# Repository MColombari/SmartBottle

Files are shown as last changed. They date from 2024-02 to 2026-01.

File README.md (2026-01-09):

# SmartBottle

Smart Bottle is a project developed by Pirelli Marco and Colombari Martina. for the course of IoT and 3D Intelligent System.
The project objective is to develop an ecosystem which help users improve their water drinking habit with an infrastructure of water dispenser and personal water bottle.

The Bottle is designed with modularity in mind, this helped achieve upgradability and reperability, while maintaining all the required feature.
The design has a very user oriented set of feature designed designed to make all the interaction as friendly and non invasive as possible, like the magnet connector to charge the system or the notification led ring that provide feedback to the user.
Thank to its modular design and open source internal architecture, we encourage user to get their hans on the system customize it.

<a target="_blank" href="https://icons8.com/icon/flyFkP7sj07V/settings">Settings</a> icon by <a target="_blank" href="https://icons8.com">Icons8</a>

<a target="_blank" href="https://icons8.com/icon/21100/refresh">Refresh</a> icon by <a target="_blank" href="https://icons8.com">Icons8</a>

## App Redesign

In this [folder](AppRedesign) you can find this system's app redesign, it contains the figma file and the relative presentation can be visualized in this [link](https://docs.google.com/presentation/d/1zaVYTiuax_qeKSTWNvRFGTr2BWS3d9cVZgYpMrOdAcI/edit?usp=sharing).

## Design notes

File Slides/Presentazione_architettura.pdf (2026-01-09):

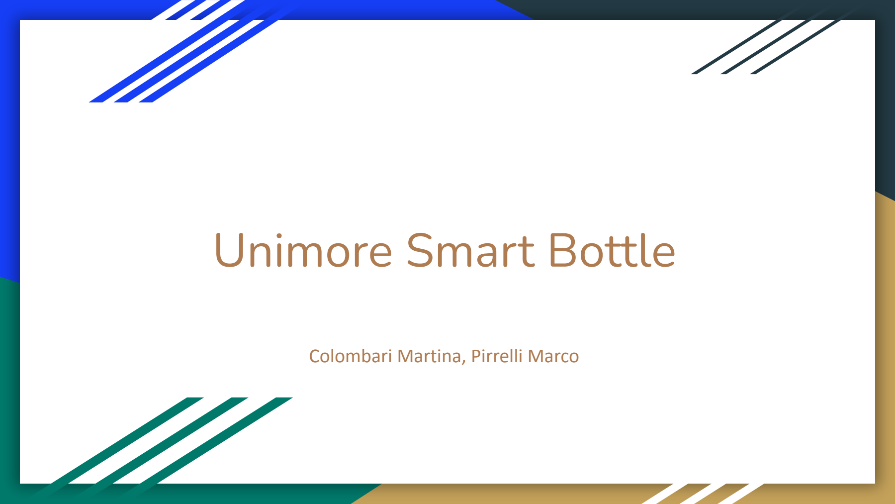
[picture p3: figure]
Unimore Smart Bottle; Colombari Martina, Pirrelli Marco

# Complete overview of the Architecture

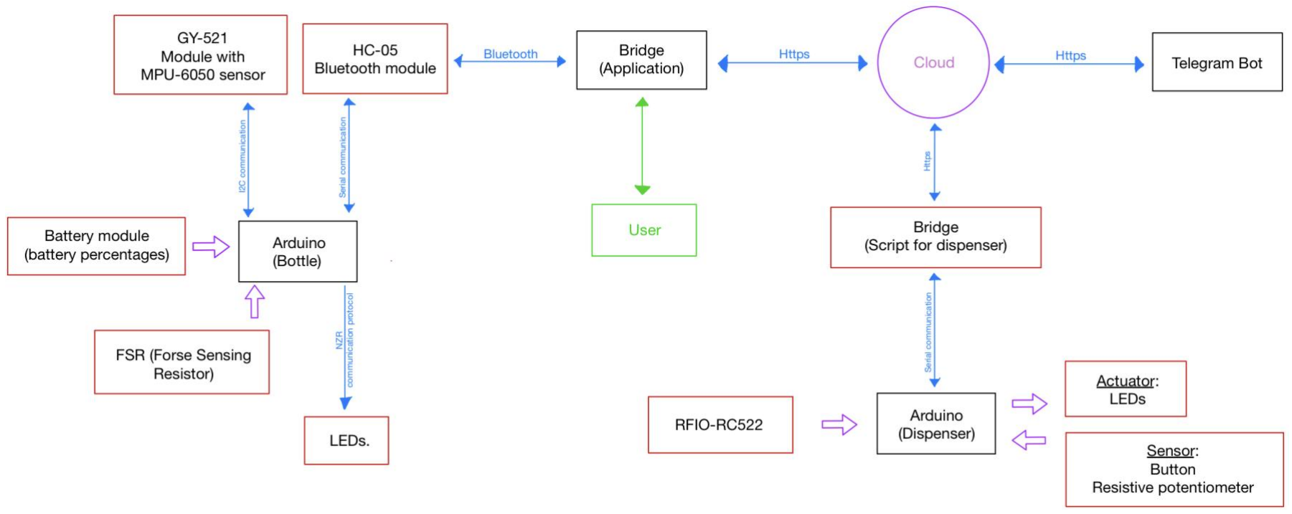
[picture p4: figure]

# Bridges

Mobile application:

- Parse the message from the bottle to the server.
- Link the user with his respective bottle, takes the Bottle ID and User ID and notify the server that that specific bottle its owned by this specific user.
- Provide a UI to show the results computed by the server.

Dispenser bridge:

- Parse the message from the dispenser to the server.
- Notify the server a malfunction if necessary.

# Communication from bridges

- HC-05 BLT Module ←→ Mobile application:
- The bottle send to the mobile application the current readings if it’s connected, they establish a serial communication with this structure:
■ <Bottle ID> ; <Weight value> ; <Battery percentage>
- The <Weight value> is the sensor reading [0-1024].
- Dispenser ←→ Dispenser bridge:
- When the dispenser is used by a user send the data to the bridge, also in this case we have a serial communication, with the following structure:
■ / <Bottle ID> - <Water level> 0xFE

# Cloud hosted server

- RESTful
- Hosted remotely on pythonanywhere.com
- Handles I/O with the database (MySQL)

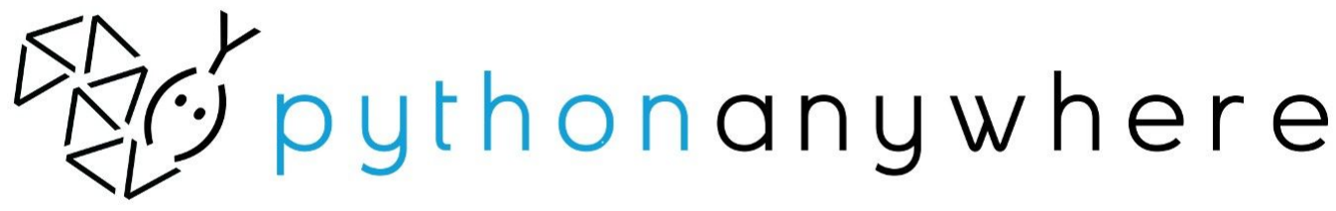
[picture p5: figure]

- Handles the bulk of calculations (such as calculating personal daily water intake)
- Has modules for dispenser engagement temporal prediction and dispenser recommendations
- Handles Telegram bot commands and data

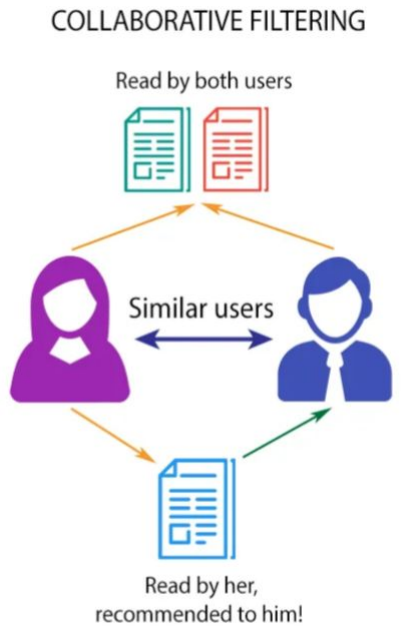
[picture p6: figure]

# Using collected data

The user data, collected through the bottles and the dispensers, can be a valuable asset.

Based upon other users’ habits it’s possible to provide recommendations - collaborative filtering approach.

The data on bottle refills is also used to predict how busy a cooler will be at a given time.

The combinations of recommendations and engagement predictions aids the redistribution of load on the dispensers.

# Telegram bot

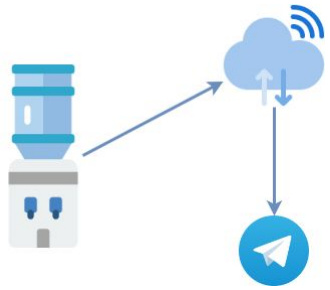
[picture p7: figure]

A simple way to notify maintenance staff of issues with the water coolers. The staff will receive new notifications sent automatically by the dispensers whenever an issue is detected.

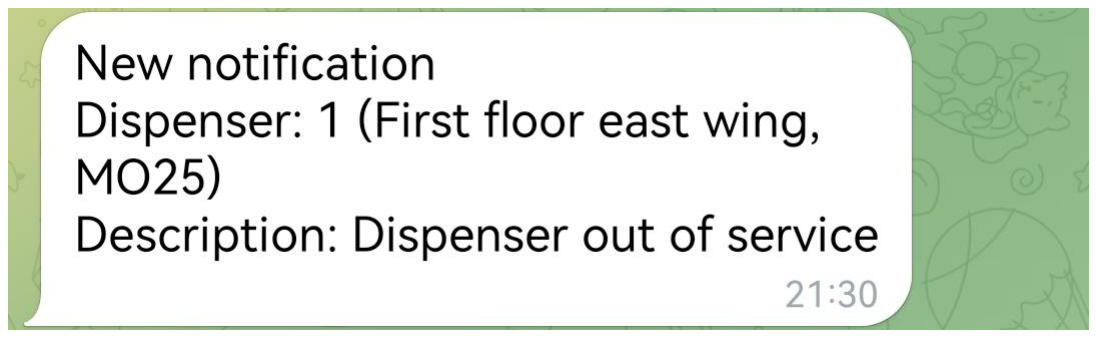
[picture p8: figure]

The maintenance staff can then proceed to delete or insert their own notifications.

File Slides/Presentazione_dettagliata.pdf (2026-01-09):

Unimore Smart Bottle; Colombari Martina, Pirrelli Marco

# Water bottle

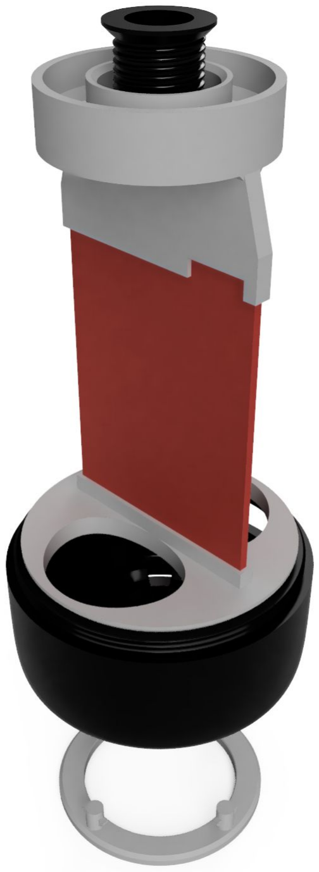
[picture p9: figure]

In the bottle we use, as a microcontroller, an Arduino Nano that communicates with different modules/sensors:

- HC-05 Bluetooth module: Serial communication, we also retrieve the status of the connection (connected or not).
- Battery module: provide battery charge.
- GY-521: Accelerometer connected with I2C.
- FSRs Force Sensing Resistor, there are each in a voltage divider, and we read the analog value.
- LEDs (addressable ws2812b led): connected with a NRZ (Non Return to Zero) protocol.

# Bottle states

Internal bottle state:

0. Idle: Starting state where the bottle is moving or not vertical, we get back to this state (form 1 or 2) if the bottle is moving or is not vertical.
1. Waiting: The bottle is steady and vertical, so now we wait before reading.
2. Reading:
a. We start reading from the weight sensor, every 300 ms, and we fill a buffer of value.
b. When the buffer is full then we send data to the application (if we have a connection), or print the values on the serial monitor.
3. Resting: after sending the data we wait to restart the cycle, this state doesn’t depend on the position of the bottle.

# Bottle flags

We define two variables to verify the state of the bottle: is_still and is_vertical. These boolean variables are updated over the values read on the GY-521

From the sensor, we obtain acceleration data for each axis. Each reading is stored in a vector of 10 elements called values_x, then, from that vector, we calculate the means and store it in another vector called means_X that we use in the end to study the bottle movement, using the mean helps reduce the noise from the sensor.

- is_still variable is obtained by calculating the max distance between two values in the means_X vector.
- is_vertical variable is obtained by calculating the mean for each axis and comparing it to a set of thresholds.

Each buffer dimension is designed to not exceed the microcontroller memory limit.

# Dispenser

The dispenser can be accessed only by our bottle, it reads the NFC tag

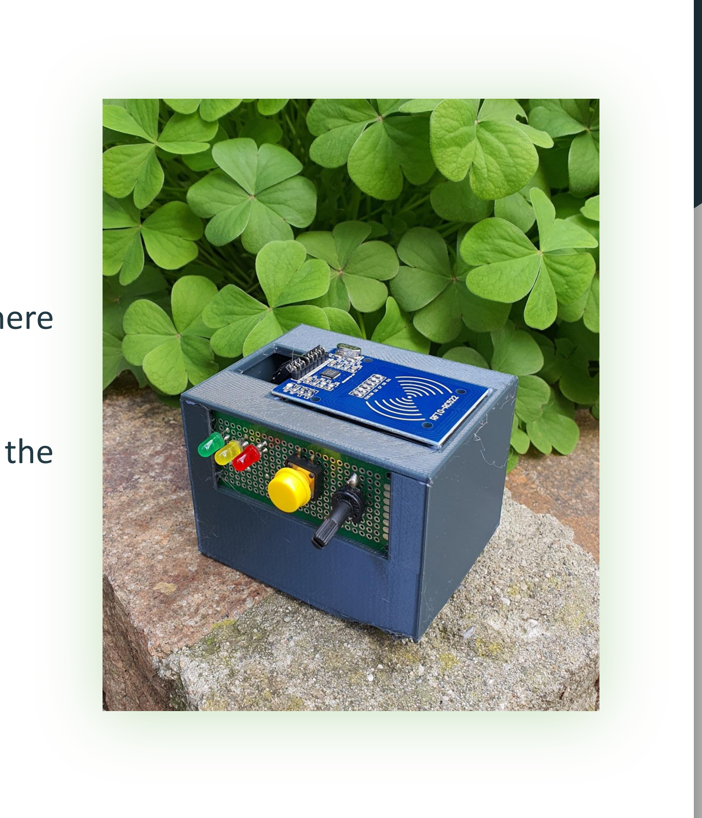
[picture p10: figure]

embedded inside the bottom of the bottle, with a RFID-RC522 sensor, where the bottle ID is stored.

For our implementation we consider a water dispenser not connected to the water system, so with a finite amount of water, we have a potentiometer that simulate the water level detected in the system.

The if the water level is too low the bridge send a distress signal to the server.

# Recommendations

When a user refills a bottle at a water cooler, the event is recorded along with the timestamp in the database. Such data is then used to construct recommendations through the python library “Implicit”.

The prediction is done with a collaborative filtering approach: rather than describing items (the dispensers) through a set of attributes and suggesting similar items to the ones a specific user has interacted with, we look for users who behave similarly to the subject and suggest items that they have enjoyed.

This approach works well in the context of water coolers because the coolers’ only distinguishing feature is their position. Nonetheless users, by interacting with them, will still create patterns.

# Engagement

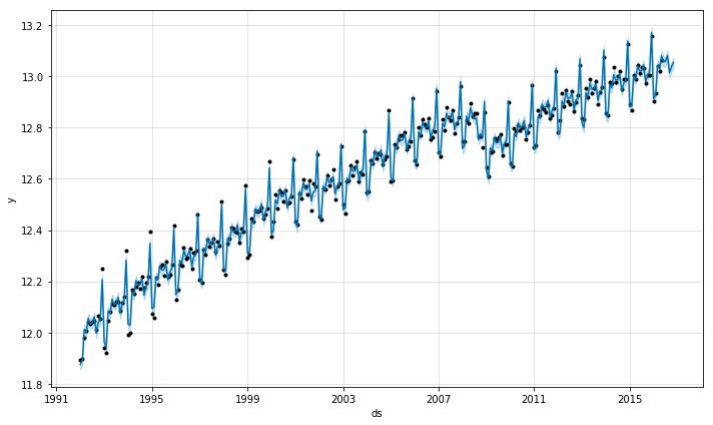
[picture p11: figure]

Another key factor in the user’s choice is how busy a cooler is.

Cooler usage data is also employed to train an engagement predictor model with the python library “fbprophet”.

The model, then, is able to calculate estimates on the amount of people that will interact with a dispenser in a particular timeframe (1 hour).

# Handling Telegram commands

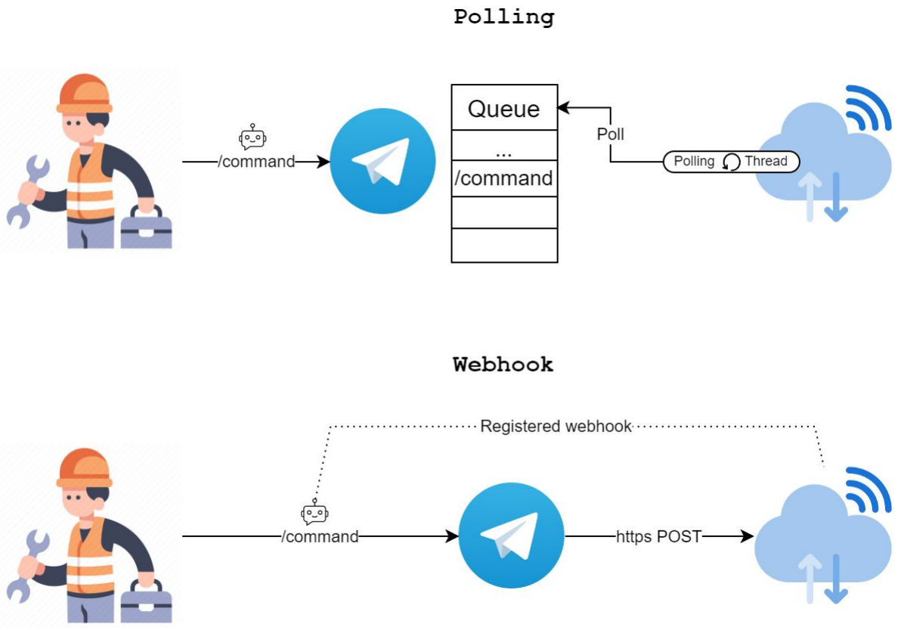
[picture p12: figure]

Telegram allows 2 paradigms for bot programming:

Polling - A dedicated thread continuously loops while polling the Telegram server for updates. Whenever the user sends a command, it is inserted in a queue and will eventually be handled.

Webhook - An https enabled web resource is linked as a webhook for the bot. Whenever a new command is sent, it immediately gets redirected to the webhook to be processed asynchronously.

Since the server is already a looping thread, a webhook paradigm fits the architecture better.

# The server

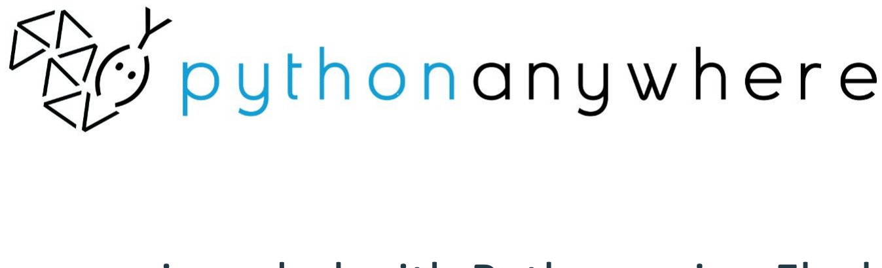
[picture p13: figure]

The server is coded with Python using Flask and is hosted remotely on pythonanywhere.com, which includes a MySQL database. The connection to the db is realized through the MySQLdb module.

The default domain at .pythonanywhere.com also automatically comes with a https certificate, which is needed to set up a Telegram webhook.

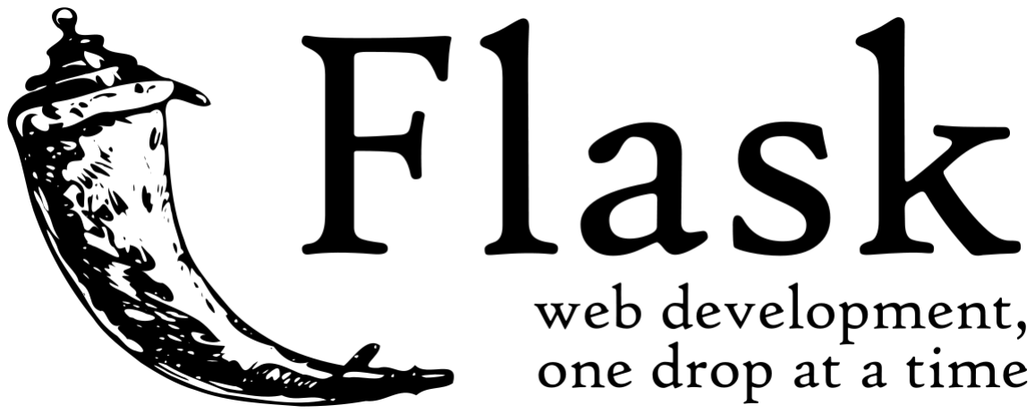
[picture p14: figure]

GET
/water_drank/<int:user_id> /recommendations/<int:user_id> /engagement/is_busy/<int:dispenser>

POST
/readings
/fills
/notifications
/bottles/register
/telegram

# Database

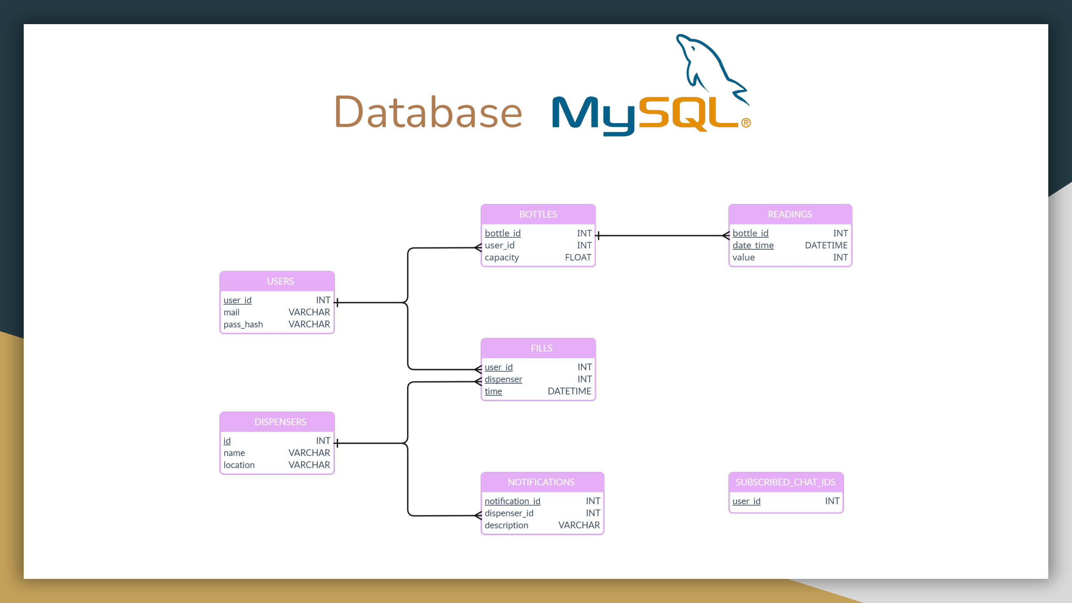
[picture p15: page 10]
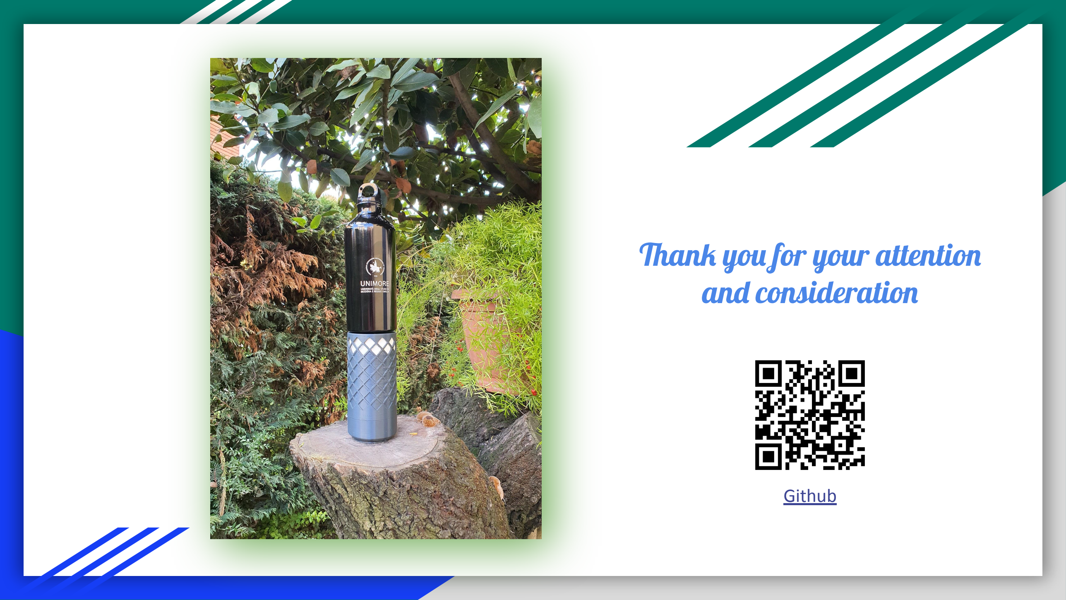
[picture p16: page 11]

# Thank you for your attention and consideration

Github (https://github.com/MColombari/SmartBottle.git)

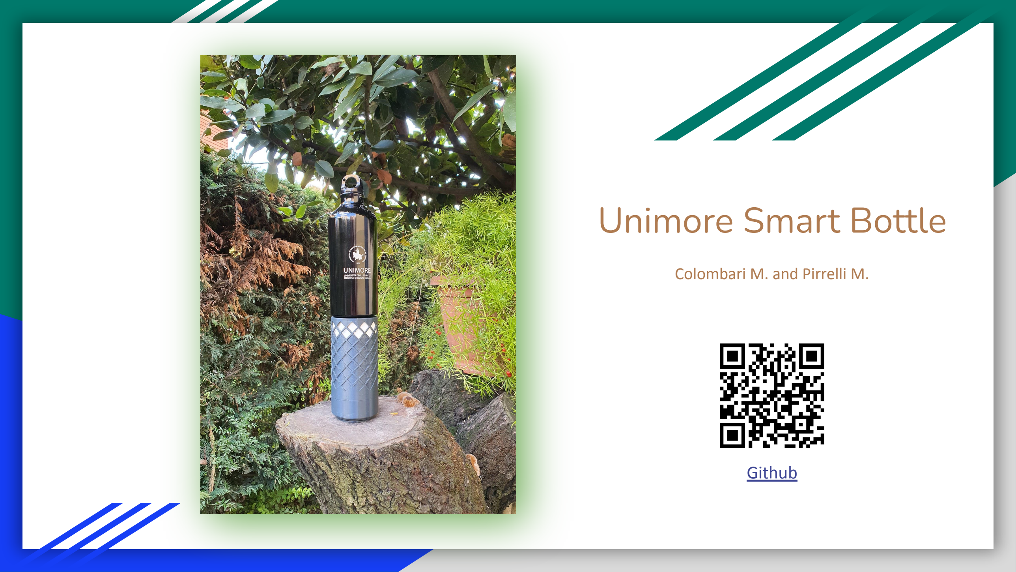
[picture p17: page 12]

Github (https://github.com/MColombari/SmartBottle.git)

# Unimore Smart Bottle

Colombari M. and Pirrelli M.

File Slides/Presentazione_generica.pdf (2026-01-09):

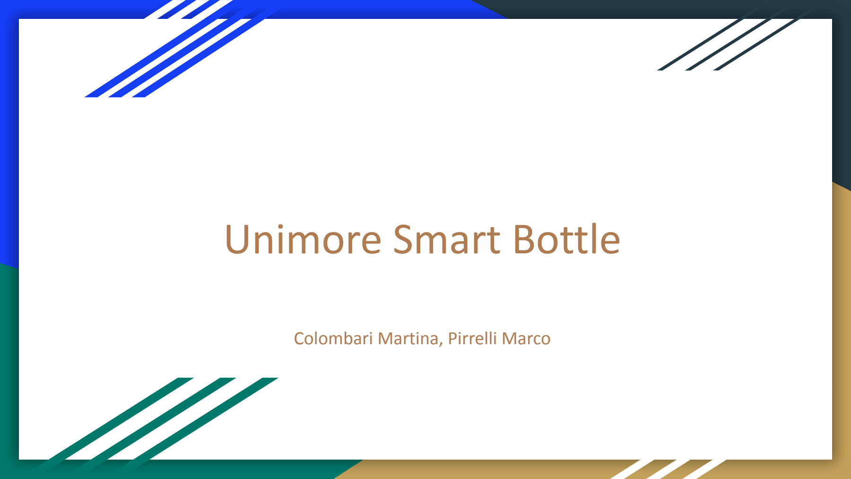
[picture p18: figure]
Unimore Smart Bottle; Colombari Martina, Pirrelli Marco

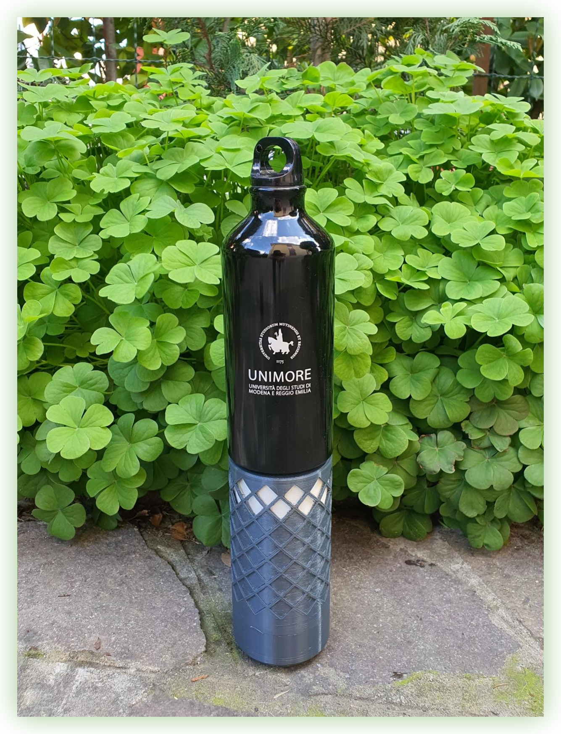
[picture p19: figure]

# Why Unimore Smart Bottle?

- In modern society, health and wellness are becoming an increasingly important part of culture
- Wellness has now fully become part a company’s brand and identity. It shows the company’s effort in creating a better environment for both its workers and clients
- Hydration is one most important factors for a person’s wellbeing

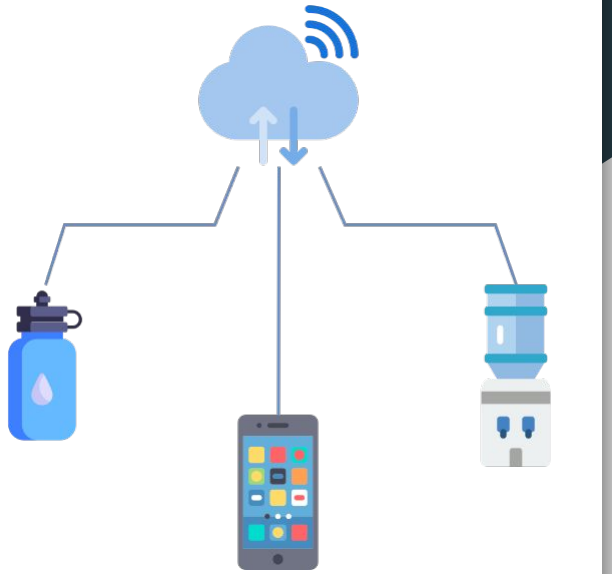
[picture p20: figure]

# What does it do?

- Allows the user to keep track of their water intake in an easy and engaging manner
- Facilitates adopting correct drinking habits
- Enables more efficient management and maintenance for a water cooler network

# The Smart Bottle

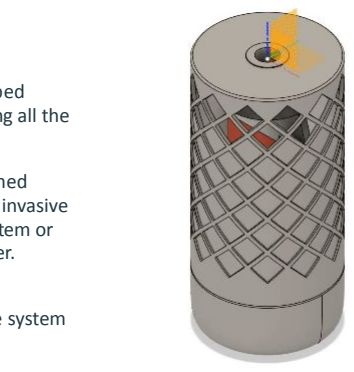
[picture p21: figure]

The Bottle is designed with modularity in mind, this helped achieve upgradability and reperability, while maintaining all the required feature.

The design has a very user oriented set of feature designed designed to make all the interaction as friendly and non invasive as possible, like the magnet connector to charge the system or the notification led ring that provide feedback to the user.

Thank to its modular design and open source internal architecture, we encourage user to get their hans on the system customize it.

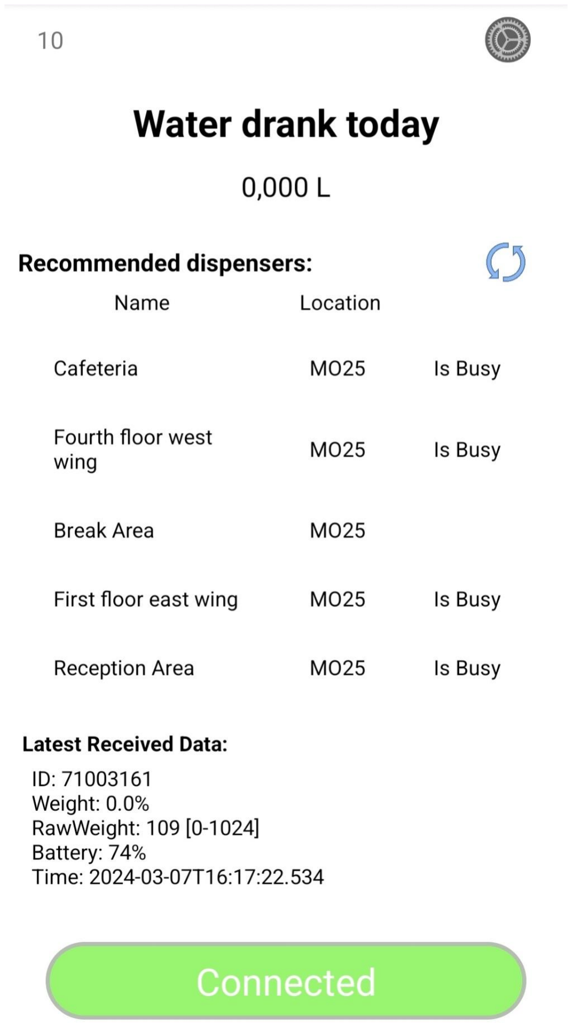
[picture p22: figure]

# Unimore Smart Bottle app

The application is the main point for the user to interact with the system:

- Shows how much water the user has drunk, so that they can reach their daily goal.
- Helps the user navigate between the available dispenser, so they can have an overview of the relevant dispenser for them, while also provide information, like location and usage statues.

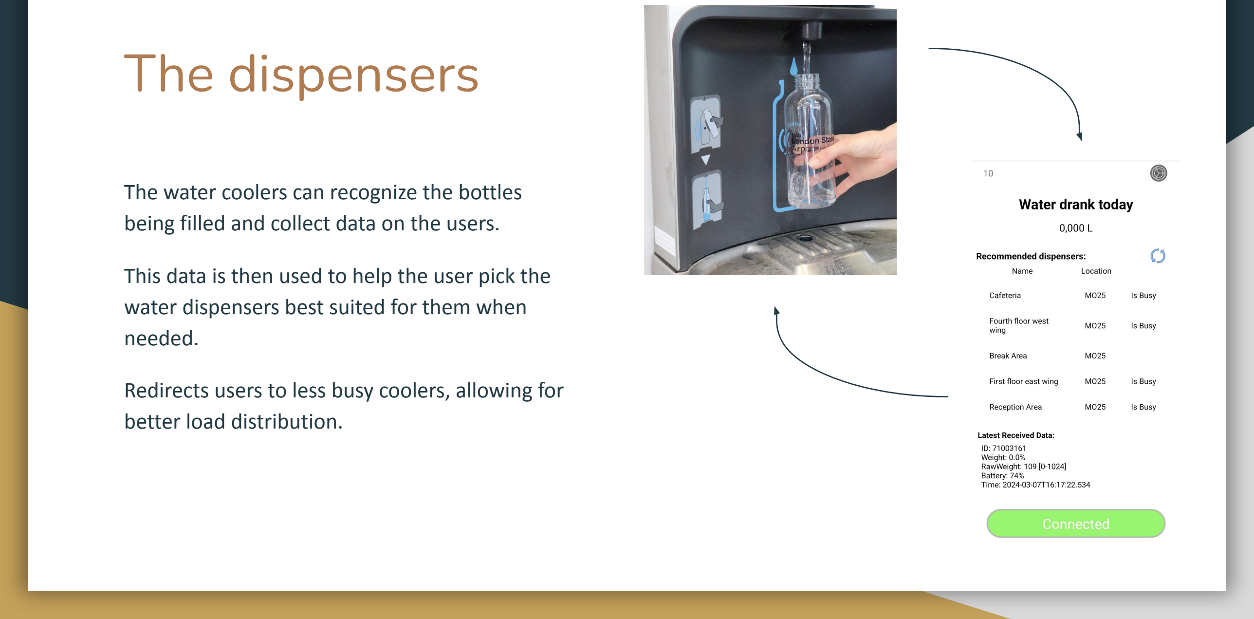
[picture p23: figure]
The dispensers; needed.; better load distribution.

The water coolers can recognize the bottles being filled and collect data on the users.

This data is then used to help the user pick the water dispensers best suited for them when

Redirects users to less busy coolers, allowing for

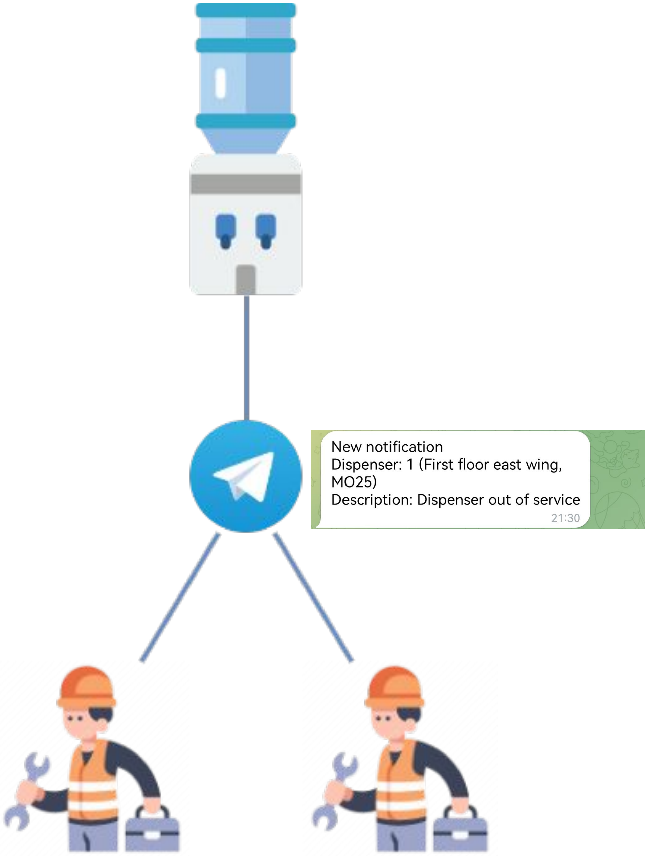
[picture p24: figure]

# Telegram integration

Whenever a water cooler detects a fault and is unable to dispense water, it automatically sends a notification through telegram to the maintenance workers.

As soon as the issue has been resolved, a worker can easily update the status of the dispenser within the Telegram app

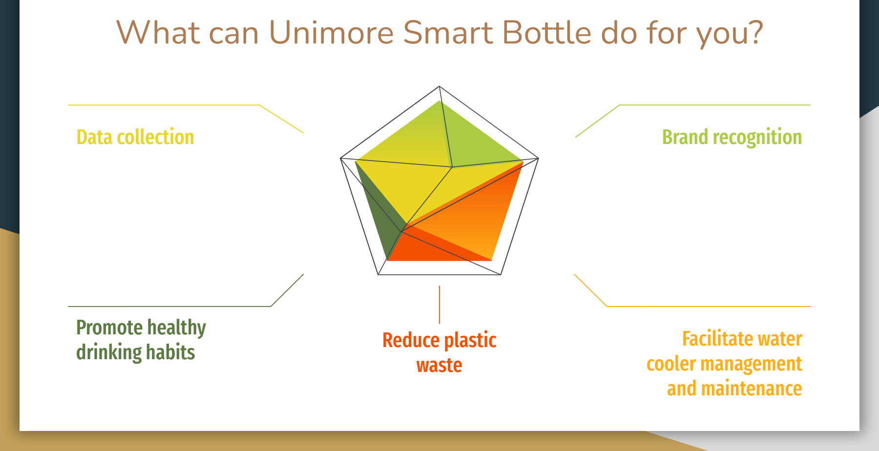
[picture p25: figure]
Data collection; Brand recognition; Promote healthy; drinking habits; Facilitate water; cooler management and maintenance; Reduce plastic waste

# What can Unimore Smart Bottle do for you?

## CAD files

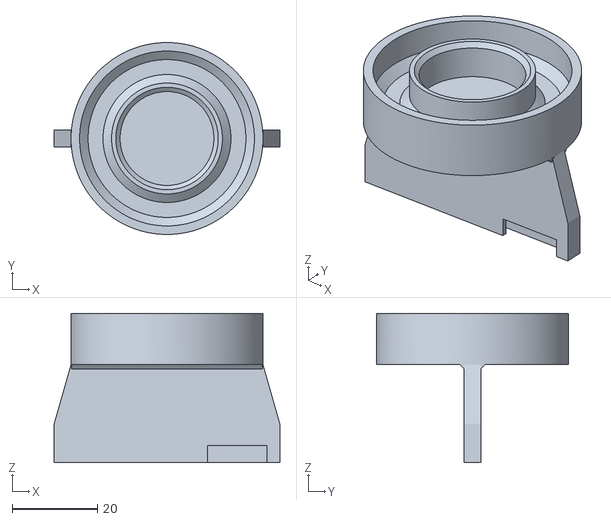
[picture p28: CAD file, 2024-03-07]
3D Files/Bottle/TopPCB.stl
53.0 x 45.0 x 35.0

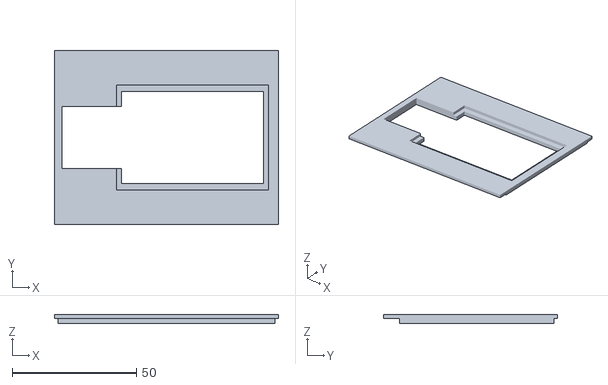
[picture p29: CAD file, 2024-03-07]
3D Files/Dispenser/Cover.stl
90.0 x 70.0 x 3.50

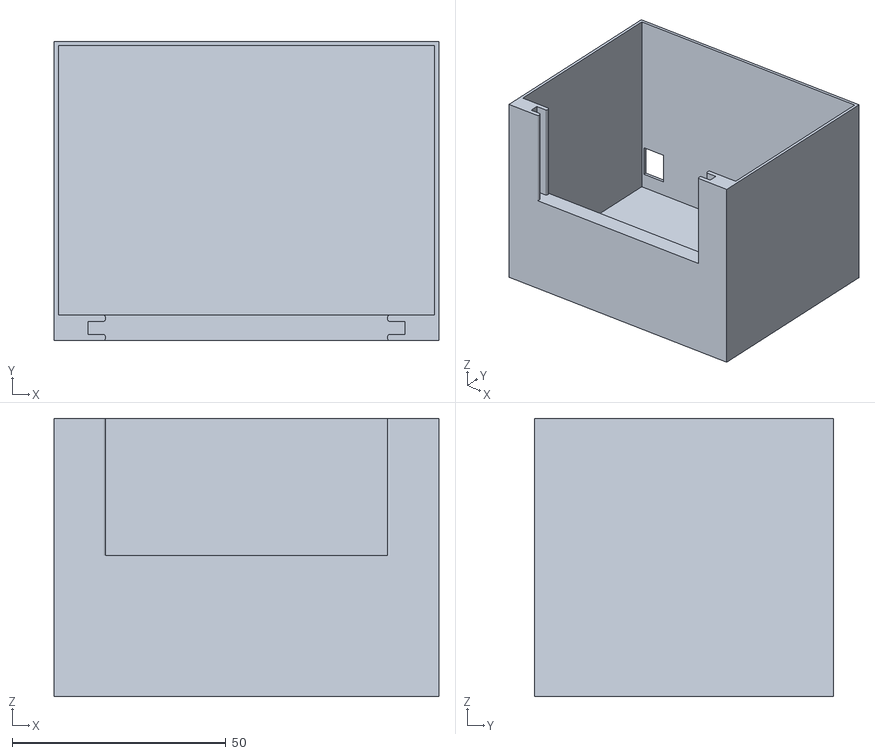
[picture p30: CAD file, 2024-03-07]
3D Files/Dispenser/Container.stl
90.0 x 70.0 x 65.0

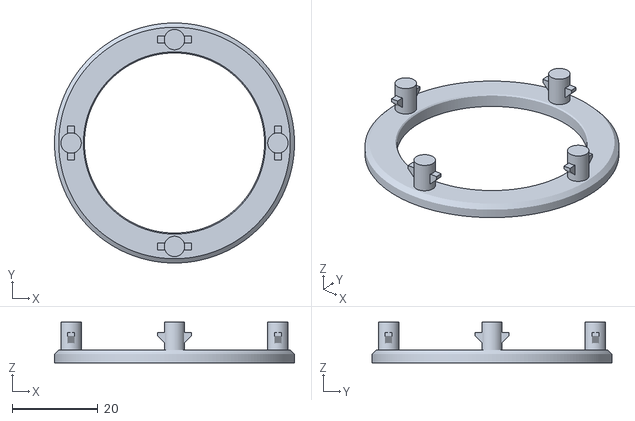
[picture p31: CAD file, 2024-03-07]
3D Files/Bottle/EmbeddedRing.stl
56.0 x 56.0 x 9.47

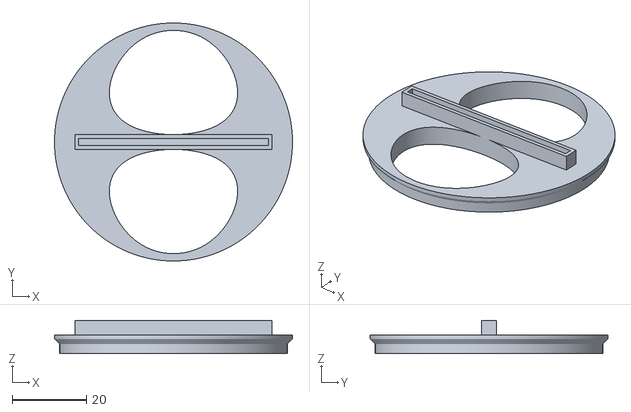
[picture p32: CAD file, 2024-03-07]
3D Files/Bottle/BottomPCB.stl
64.0 x 64.0 x 9.00

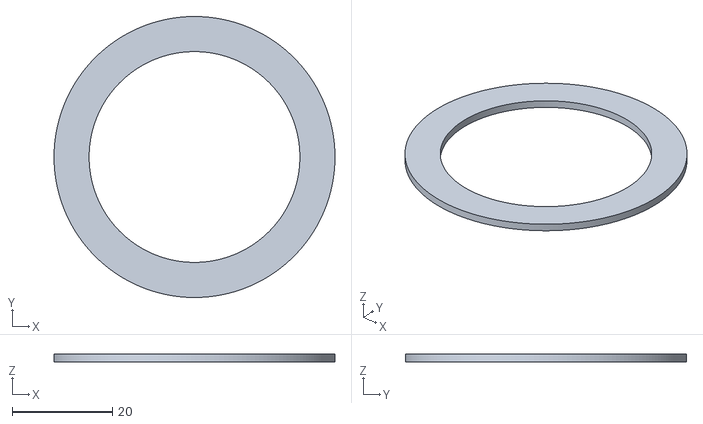
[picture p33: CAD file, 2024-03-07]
3D Files/Bottle/BottomRing.stl
56.0 x 56.0 x 1.50

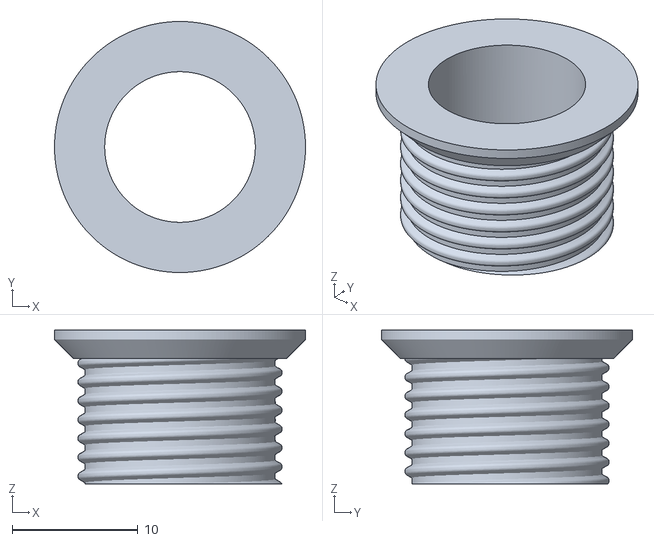
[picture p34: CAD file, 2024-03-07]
3D Files/Bottle/BottleScrew.stl
20.0 x 20.0 x 12.2

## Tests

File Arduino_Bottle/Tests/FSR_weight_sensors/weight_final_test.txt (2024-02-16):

Full		->	100%		(382)
Full-100ml	->	96%		(344)
Full-200ml	->	84%		(326)
Full-300ml	->	[72-82]%	[308-323]
Full-400ml	->	[44-50]%	[267-275]
Full-500ml	->	[34-41]%	[251-262]
Full-600ml	->	3%		(205)

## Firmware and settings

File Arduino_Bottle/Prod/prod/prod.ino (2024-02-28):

/*
      PIN Configuration
    Battery:
      A0 (Module) -> A6 (Arduino)
    Pressure:
      [A3 - A0]
      Vorltage pertition with a Pull-up resistor (10k ohm).
    HC-05:
      State -> D4.
      RX -> D3 (Pull-Down 2k, between 1k).
      TX -> D2.
    Accellerometer:
      SCL -> A5.
      SDA -> A4.
    Led:
      Control -> 11
*/

/*  -  Hyperparameter  -  */

// Generic
#define BOTTLE_ID 71003161

// GY-521
#define GY_FILTER_DIM 10
#define GY_MEANS_STORE_DIM 10
#define GY_READING_PERIOD 1
#define GY_SAVE_PERIOD 100
#define GY_UPDATE_FLAG_PERIOD 200
#define GY_G_FORCE_VALUE 17000
#define GY_G_FORCE_SLACK 1000
#define GY_ZERO_SLACK 2000
#define GY_MARGIN_DIST 150

// Battery Module
#define B_BUFFER_DIM 10
#define B_READ_PERIOD 1000
#define B_ENERGY_THRESHOLD 0.50

// Weight Sensors
#define IN_PIN_0 A0
#define IN_PIN_1 A1
#define IN_PIN_2 A2
#define IN_PIN_3 A3
#define WS_FILTER_DIMENSION 100
#define WS_IDLE_UNTIL_READ 10000
#define WS_READING_PERIOD 300      // Between read.
#define WS_IDLE_AFTER_READ 10000

// Led
#define LED_PIN 11
#define LED_NUM 20
#define LED_UPDATE_PERIOD 40


/*  -  Library include and global variable and functions  -  */

// Bluetooth
#include <SoftwareSerial.h>
#define BT_INT_PIN 4             // PIN for state.
SoftwareSerial Bluetooth(2, 3);  // TX, RX (of HC-05).

/*
void blt_print(String in){
  Serial.print(in);
  if (digitalRead(BT_INT_PIN) == HIGH) {
    Serial.println("\t\tOn BLT");
    Bluetooth.println(in);
  }
  else{
    Serial.println("\t\tOnly Serial");
  }
}
*/

// GY-521, Accellerometer.
#include <Wire.h>
#include <math.h>
#define MPU_ADDR 0x68

unsigned long start_time_read;
unsigned long start_time_save;
unsigned long start_time_update;
int16_t values_X[GY_FILTER_DIM];
int16_t values_Y[GY_FILTER_DIM];
int16_t values_Z[GY_FILTER_DIM];
int index_values;
int16_t means_X[GY_MEANS_STORE_DIM];
int16_t means_Y[GY_MEANS_STORE_DIM];
int16_t means_Z[GY_MEANS_STORE_DIM];
int index_means;
bool is_still;
bool is_vertical;

int16_t max_distance(int16_t in[], size_t dim) {
  int16_t min = in[0];
  int16_t max = in[0];
  for (size_t i = 0; i < dim; i++) {
    if (in[i] > max) { max = in[i]; }
    if (in[i] < min) { min = in[i]; }
  }
  return max - min;
}
int16_t mean(int16_t in[], size_t dim) {
  double ret = 0;
  for (size_t i = 0; i < dim; i++) {
    ret += (double)in[i];
  }
  return (int16_t)(ret / dim);
}

// Battery Module
#define sensivity (4.2 / 1023.0)
#define maxVoltage 4.2

int16_t battery_buffer[B_BUFFER_DIM];
size_t battery_buffer_index;
unsigned long b_start_time;
bool is_power_saving;

// Weight sensors
unsigned long w_start_time;

int16_t ws_values_0[WS_FILTER_DIMENSION];    // Digital filter 0.
int16_t ws_values_1[WS_FILTER_DIMENSION];    // Digital filter 1.
int16_t ws_values_2[WS_FILTER_DIMENSION];    // Digital filter 2.
int16_t ws_values_3[WS_FILTER_DIMENSION];    // Digital filter 3.
int16_t ws_index;

// Led
#include <FastLED.h>
CRGB leds[LED_NUM];
int led_intensity = 100;
int led_red = 0;
int led_green = 0;
int led_blue = 0;

unsigned long led_time;
size_t led_anim_index;
const float led_anim[] {
  0,
  0.31,
  0.59,
  0.81,
  0.94,
  1,
  0.94,
  0.81,
  0.59,
  0.31,
  0,
  0,
  0,
  0,
  0,
  0,
  0,
  0,
  0,
  0
};

void update_led(){
  if(led_anim_index >= 20){
    led_anim_index = 0;
  }
  float alpha = 0;
  for(int i = 0;  i < LED_NUM; i++){
    if((led_anim_index + i) >= LED_NUM){
      alpha = led_anim[led_anim_index + i - LED_NUM];
    }
    else{
      alpha = led_anim[led_anim_index + i];
    }

    leds[i] = CRGB(
      (int) led_blue * alpha,
      (int) led_green * alpha,
      (int) led_red * alpha);
  }
  FastLED.show();
  led_anim_index++;
}


/* Global
      0 -> Non stable.
      1 -> Wait to read.
      2 -> Reading.
      3 -> Sent.
*/
unsigned long s_time;
int state;



void setup() {
  // Serial [DEBUG]
  Serial.begin(9600);

  // Bluetooth
  Bluetooth.begin(9600);
  pinMode(BT_INT_PIN, INPUT);

  // GY-521
  Wire.begin();
  Wire.beginTransmission(MPU_ADDR);
  Wire.write(0x6B);  // PWR_MGMT_1 register
  Wire.write(0);     // set to zero (wakes up the MPU-6050)
  Wire.endTransmission(true);
  start_time_read = millis();
  start_time_save = millis();
  start_time_update = millis();
  index_values = 0;
  index_means = 0;

  for (size_t i = 0; i < GY_FILTER_DIM; i++) {
    values_X[i] = 0;
    values_Y[i] = 0;
    values_Z[i] = 0;
  }
  for (size_t i = 0; i < GY_MEANS_STORE_DIM; i++) {
    means_X[i] = 0;
    means_Y[i] = 0;
    means_Z[i] = 0;
  }

  is_still = false;
  is_vertical = false;

  // Battery Module
  battery_buffer_index = 0;
  b_start_time = millis();
  is_power_saving = false;

  for (int i = 0; i < B_BUFFER_DIM; i++) {
    battery_buffer[B_BUFFER_DIM] = 0;
  }

  // Weight Sensor
  ws_index = 0;

  for (int i = 0; i < WS_FILTER_DIMENSION; i++){
    ws_values_0[i] = 0;
    ws_values_1[i] = 0;
    ws_values_2[i] = 0;
    ws_values_3[i] = 0;
  }

  // Led
  FastLED.addLeds<WS2812B, LED_PIN, GBR>(leds, LED_NUM);
  led_anim_index = 0;
  led_time = millis();

  led_red = 10;
  led_green = 10;
  led_blue = 10;
  update_led();


  // Global
  s_time = millis();
  state = 0;
}

void loop() {
  /*
  Serial.print(state);
  Serial.print(",");
  Serial.print(is_vertical);
  Serial.print(",");
  Serial.println(is_still);*/
  //Bluetooth.println(state);
  
  // blt_print(String(state) + "");

  // Index Update.
  if (index_values >= GY_FILTER_DIM) {
    index_values = 0;
  }
  if (index_means >= GY_FILTER_DIM) {
    index_means = 0;
  }
  if (battery_buffer_index >= B_BUFFER_DIM) {
    int16_t value = mean(battery_buffer, B_BUFFER_DIM);
    if (value <= B_ENERGY_THRESHOLD) {
      is_power_saving = true;
    } else {
      is_power_saving = false;
    }
    battery_buffer_index = 0;
  }

  //Serial.println(state);

  //Led update
  if((millis() - led_time) >= LED_UPDATE_PERIOD){
    if(state == 0){
      led_red = 10;
      led_green = 10;
      led_blue = 10;
    }
    else if(state == 1){
      led_red = 10;
      led_green = 0;
      led_blue = 0;
    }
    else if(state == 2){
      led_red = 0;
      led_green = 0;
      led_blue = 10;
    }
    else{
      led_red = 0;
      led_green = 10;
      led_blue = 0;
    }
    update_led();
    led_time = millis();
  }

  if(((state == 1) || (state == 2)) && (!is_vertical || !is_still)){
    ws_index = 0;
    state = 0;
    s_time = millis();
  }

  if((state == 0) && (is_still && is_vertical)){
    state = 1;
    s_time = millis();
  }

  if((state == 1) && ((millis() - s_time) >= WS_IDLE_UNTIL_READ)){
    state = 2;
    s_time = millis();
    ws_index = 0;
    for (int i = 0; i < WS_FILTER_DIMENSION; i++){
      ws_values_0[i] = 0;
      ws_values_1[i] = 0;
      ws_values_2[i] = 0;
      ws_values_3[i] = 0;
    }
  }

  if((state == 2) && ((millis() - s_time) >= WS_READING_PERIOD)){
    ws_values_0[ws_index] = analogRead(IN_PIN_0);
    ws_values_1[ws_index] = analogRead(IN_PIN_1);
    ws_values_2[ws_index] = analogRead(IN_PIN_2);
    ws_values_3[ws_index] = analogRead(IN_PIN_3);
    ws_index++;
    s_time = millis();
  }

  if((ws_index >= WS_FILTER_DIMENSION - 1) && (state == 2)){
    Serial.println("Sending...");
    // Send Data
    int tot_means[4];
    tot_means[0] = mean(ws_values_0, WS_FILTER_DIMENSION);
    tot_means[1] = mean(ws_values_1, WS_FILTER_DIMENSION);
    tot_means[2] = mean(ws_values_2, WS_FILTER_DIMENSION);
    tot_means[3] = mean(ws_values_3, WS_FILTER_DIMENSION);
    int tot = tot_means[0] + tot_means[1] + tot_means[2] + tot_means[3];
    tot /= 4;

    int16_t battery_value = mean(battery_buffer, B_BUFFER_DIM);

    //Serial.println("Calc Complete");

    //String out = "Battery: " + String(battery_value) + "\n" "Weight: " + String(map(tot, 1024, 0, 0, 100)) + "%";

    Serial.print("Battery: ");
    Serial.print(battery_value);
    Serial.print("%;");
    Serial.print("Weight: ");
    Serial.print(tot);
    Serial.println("%");
    //Serial.println(digitalRead(BT_INT_PIN) == HIGH);
    if (digitalRead(BT_INT_PIN) == HIGH) {
      Bluetooth.print(BOTTLE_ID);
      Bluetooth.print(";");
      Bluetooth.print(map(tot, 1024, 0, 0, 1024));
      Bluetooth.print(";");
      Bluetooth.println(battery_value);
      Serial.println("\tOn Bluetooth");
    }
    else{
      Serial.println("\tOnly Serial");
    }

    ws_index = 0;
    state = 3;
    s_time = millis();
  }

  if((state == 3) && ((millis() - s_time) >= WS_IDLE_AFTER_READ)){
    state = 0;
    s_time = millis();
  }

  // Read value from the MPU.
  if (GY_READING_PERIOD <= millis() - start_time_read) {
    Wire.beginTransmission(MPU_ADDR);
    Wire.write(0x3B);  // starting with register 0x3B (ACCEL_XOUT_H)
    Wire.endTransmission(false);
    Wire.requestFrom(MPU_ADDR, 6, true);                      // request a total of 6 registers
    values_X[index_values] = Wire.read() << 8 | Wire.read();  // 0x3B (ACCEL_XOUT_H) & 0x3C (ACCEL_XOUT_L)
    values_Y[index_values] = Wire.read() << 8 | Wire.read();  // 0x3D (ACCEL_YOUT_H) & 0x3E (ACCEL_YOUT_L)
    values_Z[index_values] = Wire.read() << 8 | Wire.read();  // 0x3F (ACCEL_ZOUT_H) & 0x40 (ACCEL_ZOUT_L)

    index_values++;
    start_time_read = millis();
  }

  // Save data read from the MPU.
  if (GY_SAVE_PERIOD <= millis() - start_time_save) {
    means_X[index_means] = mean(values_X, GY_FILTER_DIM);
    means_Y[index_means] = mean(values_Y, GY_FILTER_DIM);
    means_Z[index_means] = mean(values_Z, GY_FILTER_DIM);

    /*  Debug
    Serial.print(means_X[index_means]); Serial.print(",");
    Serial.print(means_Y[index_means]); Serial.print(",");
    Serial.print(means_Z[index_means]); Serial.print(",");
    Serial.print(is_still); Serial.print(",");
    Serial.println(is_vertical); */

    index_means++;
    start_time_save = millis();
  }

  // Update "is_vertical" and "is_still" flag.
  if (GY_UPDATE_FLAG_PERIOD <= millis() - start_time_update) {
    int16_t mean_X = mean(means_X, GY_MEANS_STORE_DIM);
    int16_t mean_Y = mean(means_Y, GY_MEANS_STORE_DIM);
    int16_t mean_Z = mean(means_Z, GY_MEANS_STORE_DIM);

    // Check if it's verical.
    if (
      ((mean_X >= -GY_ZERO_SLACK) && (mean_X <= GY_ZERO_SLACK)) && ((mean_Y >= -GY_ZERO_SLACK) && (mean_Y <= GY_ZERO_SLACK)) && ((mean_Z >= GY_G_FORCE_VALUE - GY_G_FORCE_SLACK) && (mean_Z <= GY_G_FORCE_VALUE + GY_G_FORCE_SLACK))) {
      // Print if changed.
      /*
      if (is_vertical == false) {
        blt_print("Is vertical");
      }
      */
      is_vertical = true;
    } else {
      /*
      if (is_vertical == true) {
        blt_print("Is NOT vertical");
      }
      */
      is_vertical = false;
    }

    // check if it's still.
    int16_t dist_X = max_distance(means_X, GY_MEANS_STORE_DIM);
    int16_t dist_Y = max_distance(means_X, GY_MEANS_STORE_DIM);
    int16_t dist_Z = max_distance(means_X, GY_MEANS_STORE_DIM);

    if (
      (dist_X <= GY_MARGIN_DIST) && (dist_Y <= GY_MARGIN_DIST) && (dist_Z <= GY_MARGIN_DIST)) {
      /*
      if (is_still == false) {
        //Serial.println("[GY-521]: Is still");
        blt_print("Is still");
      }
      */
      is_still = true;
    } else {
      /*
      if (is_still == true) {
        //Serial.println("[GY-521]: Is NOT still");
        blt_print("Is NOT still");
      }
      */
      is_still = false;
    }

    start_time_update = millis();
  }

  // Read battery value.
  if (millis() >= b_start_time + B_READ_PERIOD) {
    float sensorValue = analogRead(A6);                     // Raw value.
    sensorValue = sensorValue * sensivity;                  // Voltage.
    float percentage = (sensorValue / maxVoltage) * 100.0;  // Percentage.
    battery_buffer[battery_buffer_index] = (int16_t)percentage;
    battery_buffer_index++;
    b_start_time = millis();
  }
}

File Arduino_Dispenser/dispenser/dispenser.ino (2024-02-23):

#include <SPI.h>
#include <MFRC522.h>


// Pin connection RC522:
/*
    SDA   ->    D10
    SCK   ->    D13
    MOSI  ->    D11
    MISO  ->    D12
    RST   ->    D9
*/


#define SS_PIN 10
#define RST_PIN 9

#define BUTTON_PIN 5

#define WL_PIN 7  // Analog pin, Water Level.

#define R_LED_PIN 4
#define Y_LED_PIN 3
#define G_LED_PIN 2

#define UID_LENGHT 7
#define UID_TO_PRINT 4

#define TIME_AFTER_FAILURE 1000
#define TIME_AFTER_SUCCESS 500

const char* START_STRING = "/";
const char* SEPARATOR_STRING = "-";

int state;
unsigned long t_fail;
unsigned long t_success;
byte UID[UID_LENGHT];

/*  State table
    0 -> IDLE.
    1 -> UID identified.
    2 -> Failure.
*/

MFRC522 rfid(SS_PIN, RST_PIN);

void setup() {
  Serial.begin(9600);
  SPI.begin(); // init SPI bus
  rfid.PCD_Init(); // init MFRC522

  //Serial.println(rfid.PCD_GetAntennaGain());
  rfid.PCD_SetRegisterBitMask(rfid.RFCfgReg, (0x07<<4)); // Increase antenna gain to 48db.
  //Serial.println(rfid.PCD_GetAntennaGain());

  pinMode(BUTTON_PIN, INPUT);
  pinMode(R_LED_PIN, OUTPUT);
  pinMode(Y_LED_PIN, OUTPUT);
  pinMode(G_LED_PIN, OUTPUT);

  digitalWrite(R_LED_PIN, LOW);
  digitalWrite(Y_LED_PIN, HIGH);
  digitalWrite(G_LED_PIN, LOW);

  state = 0;
  t_fail = millis();
  t_success = millis();
}

void send_data(){
  Serial.write(START_STRING);
  for(int i = 0; i < UID_TO_PRINT; i++){
    if(rfid.uid.uidByte[i] < 0x10){
      Serial.print("0");
    }
    Serial.print(rfid.uid.uidByte[i], HEX);
  }
  Serial.print(SEPARATOR_STRING);
  Serial.print(map(analogRead(WL_PIN), 0, 1023, 0, 100));
  Serial.write(0xFE);
}

void loop() {
  if((state == 2) && ((millis() - t_fail) > TIME_AFTER_FAILURE)){
    // Back to idle.
    state = 0;
    digitalWrite(R_LED_PIN, LOW);
    digitalWrite(Y_LED_PIN, HIGH);
    digitalWrite(G_LED_PIN, LOW);
  }
  if((digitalRead(BUTTON_PIN) == HIGH) && ((millis() - t_success) > TIME_AFTER_SUCCESS)){
    if(state == 1){
      send_data();
      // Back to idle.
      state = 0;
      digitalWrite(R_LED_PIN, LOW);
      digitalWrite(Y_LED_PIN, HIGH);
      digitalWrite(G_LED_PIN, LOW);
      t_success = millis();
    }
    else{
      // Failure state.
      state = 2;
      digitalWrite(R_LED_PIN, HIGH);
      digitalWrite(Y_LED_PIN, LOW);
      digitalWrite(G_LED_PIN, LOW);
      t_fail = millis();
    }
  }
  if (rfid.PICC_IsNewCardPresent()) { // new tag is available
    if (rfid.PICC_ReadCardSerial()) { // NUID has been readed

      MFRC522::PICC_Type piccType = rfid.PICC_GetType(rfid.uid.sak);

      if(rfid.uid.size != UID_LENGHT){
        // Failure
        state = 2;
        digitalWrite(R_LED_PIN, HIGH);
        digitalWrite(Y_LED_PIN, LOW);
        digitalWrite(G_LED_PIN, LOW);
        t_fail = millis();
      }
      else{
        for (int i = 0; i < rfid.uid.size; i++) {
          UID[i] = rfid.uid.uidByte[i];
          // Serial.println(rfid.uid.uidByte[i], HEX); Debug
        }
        state = 1;
        digitalWrite(R_LED_PIN, LOW);
        digitalWrite(Y_LED_PIN, LOW);
        digitalWrite(G_LED_PIN, HIGH);
      }

      rfid.PICC_HaltA(); // halt PICC
      rfid.PCD_StopCrypto1(); // stop encryption on PCD
    }
  }
}

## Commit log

2023-11-30 Improved for 4 sensor, and multiplotting in Arduino serial.
2023-12-01 Test of GY-521 sensor
2023-12-01 Improved test GY-521
    Now we defined 2 flag to check if the sensor is vertical and/or still.
2023-12-03 Battery Module test
2023-12-15 Fixed and tuned complete board test
    Now can show in serial terminal and bluetooth connection if he's still and/or vertical.
    [Complete_Board_Test.ino, Test_Gy-521.ino]
2024-01-07 Added dispenser_bridge.py
    Aggiunto dispenser_bridge.py
    Manca la connessione seriale
2024-01-09 Arduino dispenser code
2024-01-09 Pin update
2024-01-09 Removed debug print
2024-02-19 Added bottle to user linking
    Added method registerBottle(int bottleId, int userId, double capacity)
2024-02-21 Multiple thread to update IsDispenserBusy, refresh button and auto refresh when new id is defined.
2024-02-23 Send Data to Server and arduino new communication protocol with the app.
2024-02-23 Fixed ID dimension and bottle parameter
    [dispenser.ino, dispenser_bridge.py, prod.ino]
2024-02-25 Bottle capacity bug fix.
2024-03-07 3D Files added.
    [BottomRing.stl]
2024-03-07 More 3D files.
    [BottleScrew.stl, BottomPCB.stl, Container.stl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]
2024-05-08 Arduino test changes
